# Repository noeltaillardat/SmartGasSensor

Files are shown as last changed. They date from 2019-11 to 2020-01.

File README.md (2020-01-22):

# SmartGasSensor
#### Arduino shield with gas sensing and LoRa connection.

On this github, you will find KiCad files to print your PCB and Arduino files to upload code to use the shield.

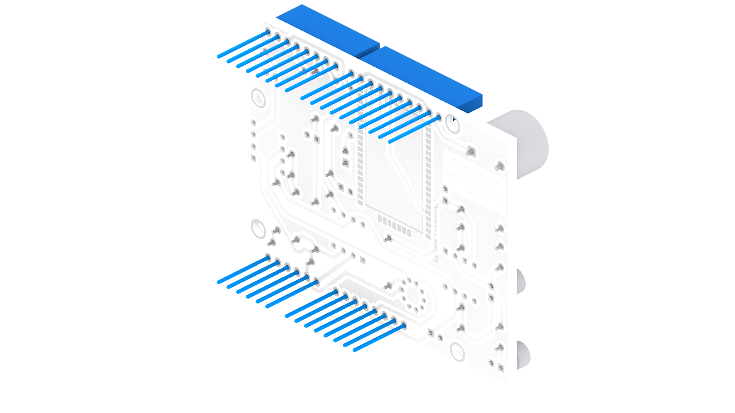
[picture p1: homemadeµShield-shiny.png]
Shield


## Functionalities
* Gas sensor + Electrical noise reduction + Temperature setting
* Warning trigger + visual warning 
* LoRa communication + TTN connection
* Buzzer can be activated

### Gas sensor + Electrical noise reduction
Gas sensor made at the AIME whiteroom of Toulouse.

On the shield, filters are made to reduce the electrical noise. There is a passive filter to cancel HF noise at the start of the circuit. An active filter with an Op-Amp is on to be more efficient. The gain can be modified with the potentiometer named *PT1*.
A passive filter at the end of the circuit is used to filter noise induced by the circuit.

The temperature can be set to improve gas recognition with *Gas_Temp_Target*.
The feedback loop gain can be modified with the *PT2* potentiometer.

### LoRa communication + TTN connection
You will find as well *ttn_script.js* to use on the TheThingsNetwork console to decrypt the data.

The Arduino code needs to be updated with your app and network session key foundable on the TTN console.
The activation method needs to be set to ABP. 

### Warning trigger + visual warning 
The warning can be set with *Gas_Trigger_Offset* to set the estimated thresold value.

An hysteresis has been made to be sure that the warning do not go on and on multiple times. 
This can be set with *Gas_Trigger_Diff*.
In case of limited amplitude of the hysteresis, the potentiometers *PT3* and *PT4* can be changed to adapt it to your use.

A LED on board have visual indication of the warning

### Buzzer can be activated
A buzzer can be activated with a *analogWrite* command.

A usage would be to set it to ring when the warning goes on, or when the warning is on.
Another can be to ring when the LoRa connection fails.

## Routing & schematics

Below is the schematic of our shield, including all the features explained above.

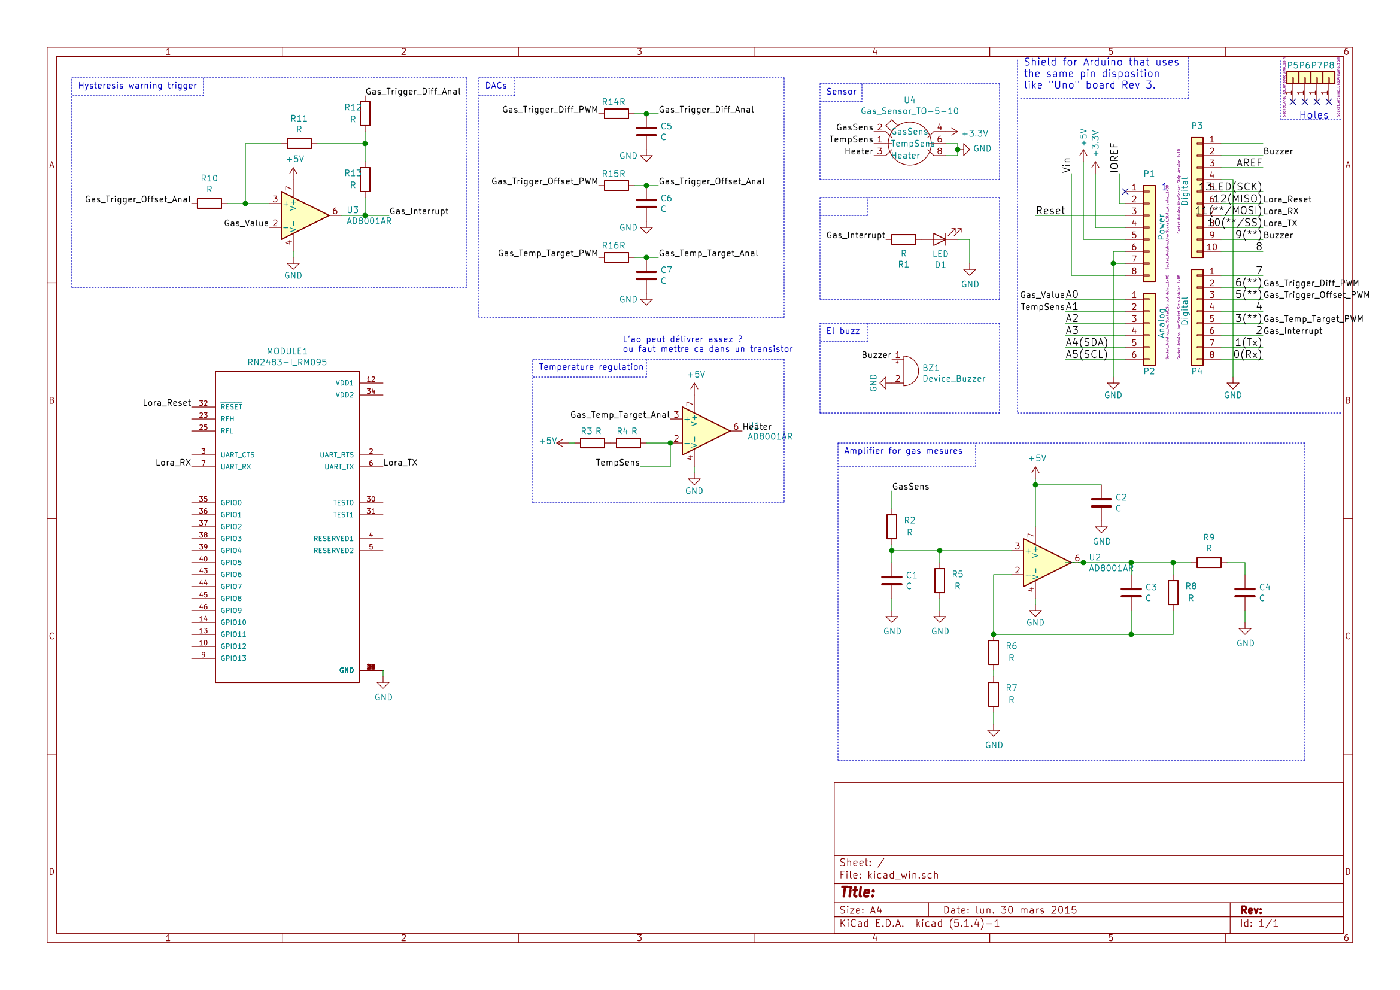
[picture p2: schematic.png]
Schematic


From there, the routing of our shield is achieved as shown below:

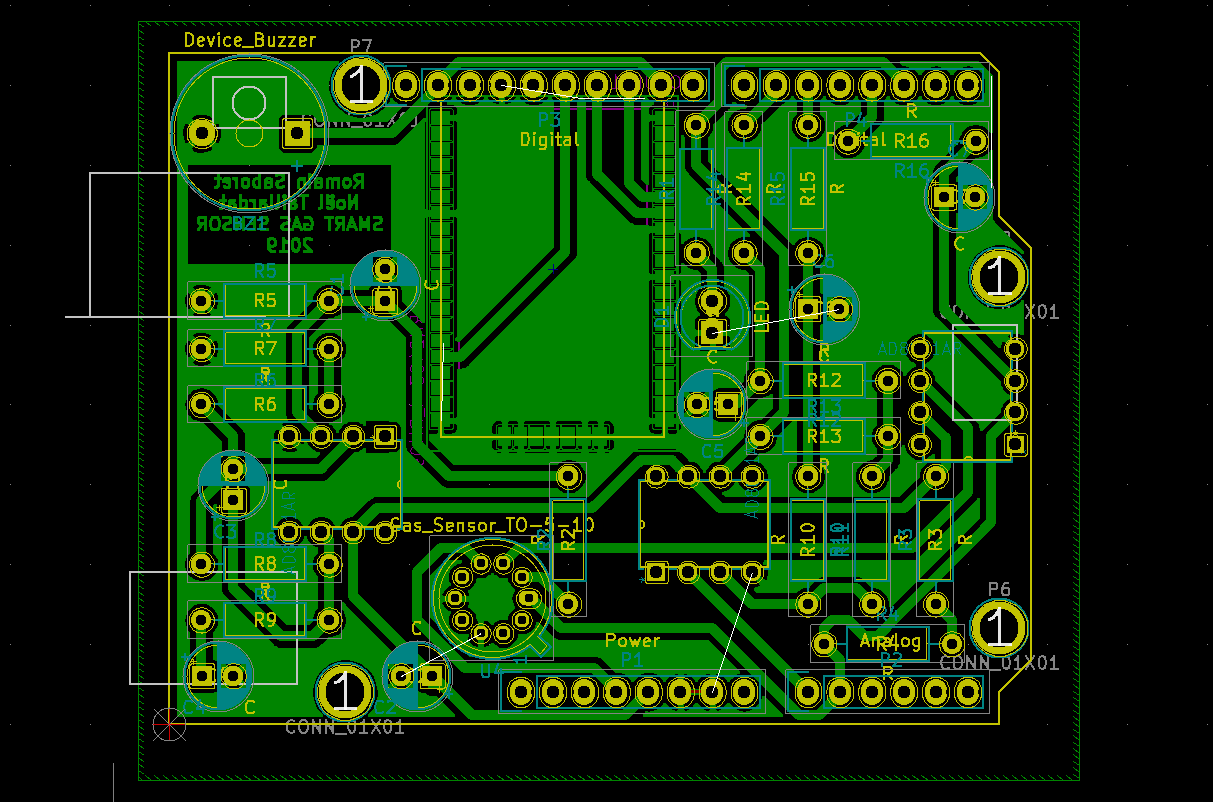
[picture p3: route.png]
Routes


Here, a 3D view (from Blender) of the shield: 

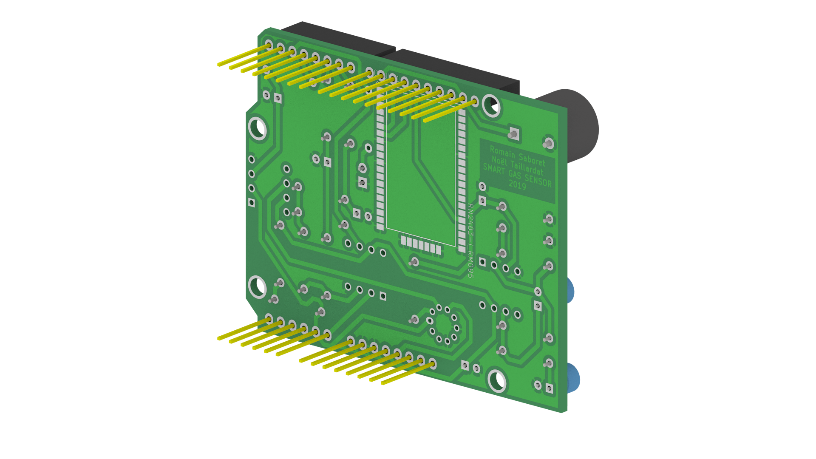
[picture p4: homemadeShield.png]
Final view


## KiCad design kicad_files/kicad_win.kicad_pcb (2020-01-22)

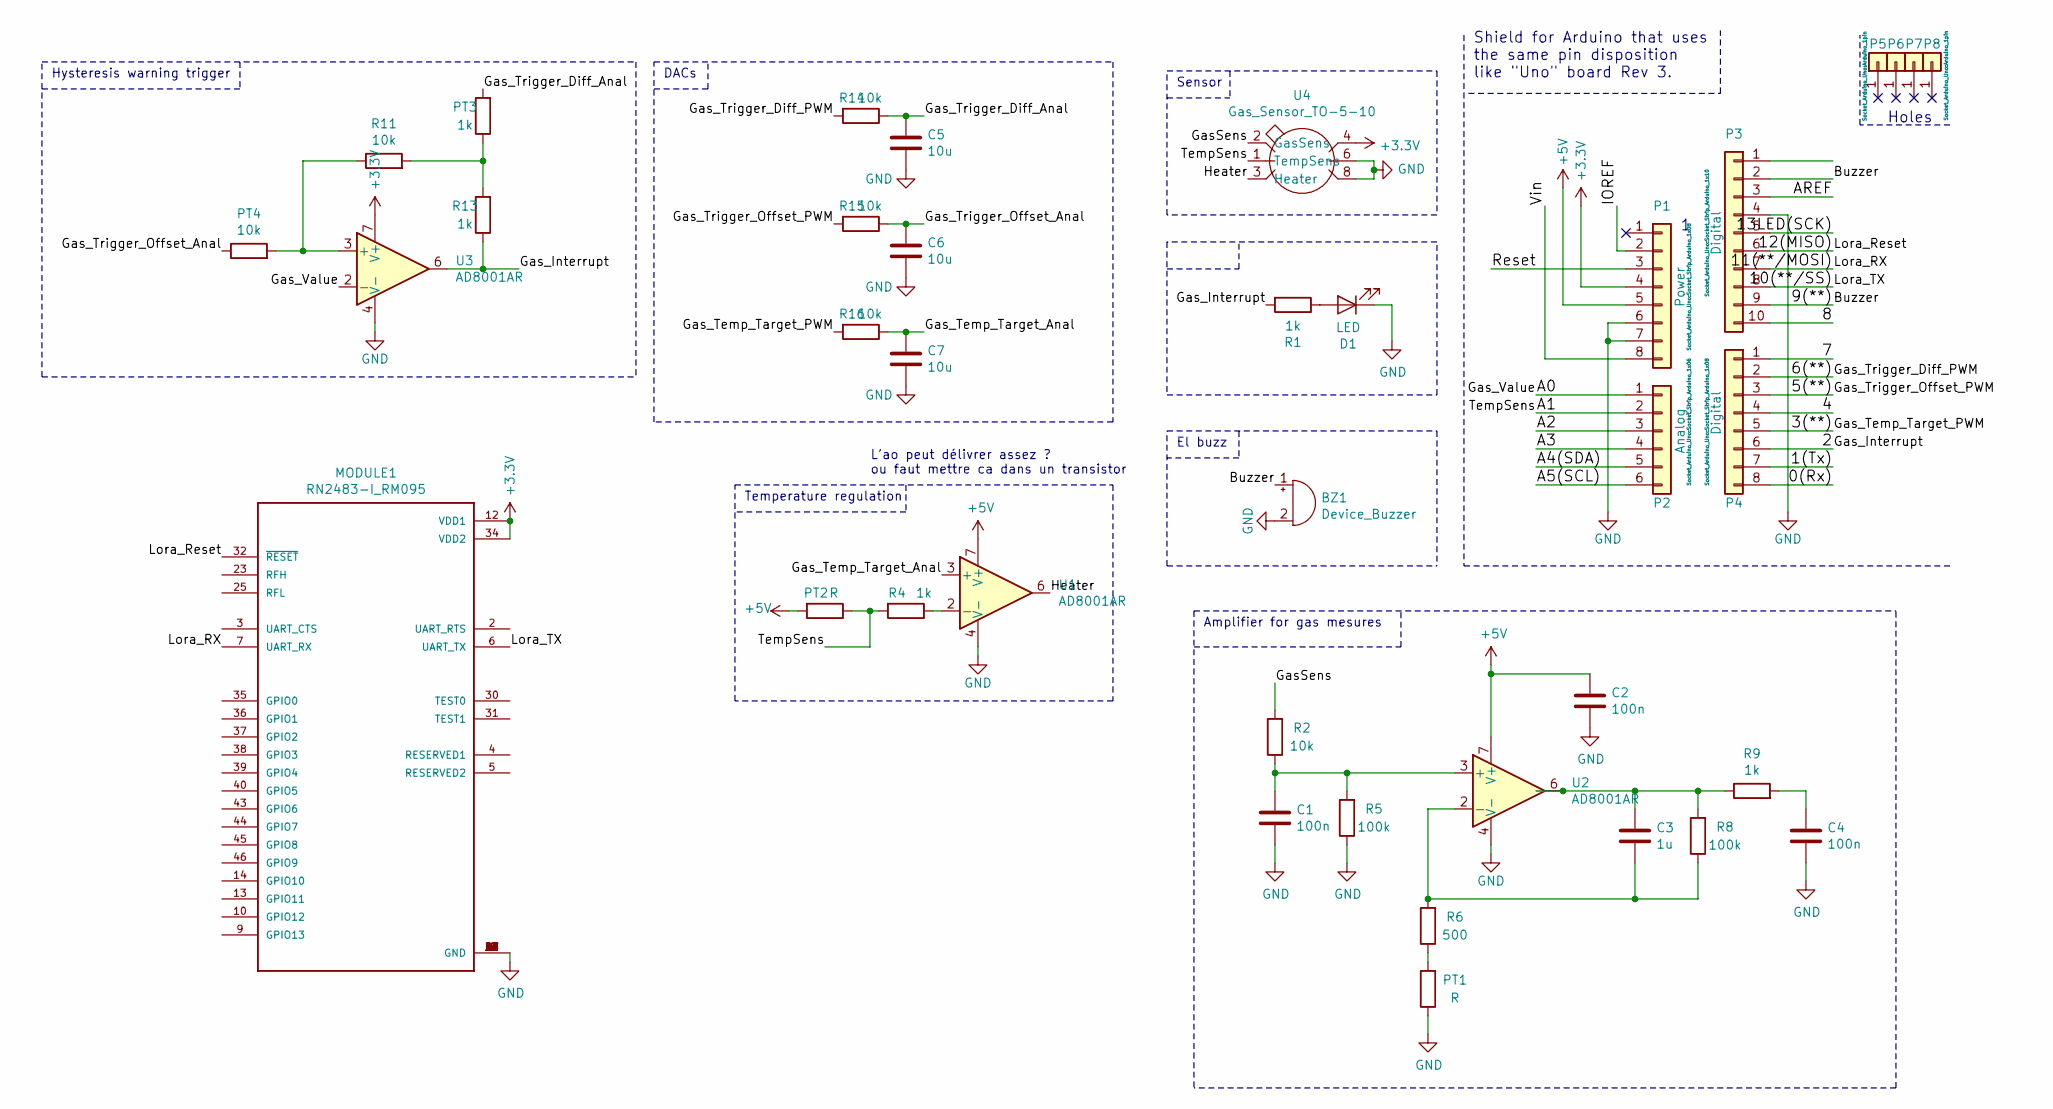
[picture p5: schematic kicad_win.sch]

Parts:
BZ1: Device_Buzzer; Buzzer_12x9.5RM7.6
C1, C2, C4: 100n; CP_Radial_D5.0mm_P2.50mm
C3: 1u; CP_Radial_D5.0mm_P2.50mm
C5, C6, C7: 10u; CP_Radial_D5.0mm_P2.50mm
D1: LED; LED_D5.0mm
MODULE1: RN2483-I_RM095; MICROCHIP_RN2483-I%2fRM095
P1: Power; Socket_Strip_Arduino_1x08
P2: Analog; Socket_Strip_Arduino_1x06
P3: Digital; Socket_Strip_Arduino_1x10
P4: Digital; Socket_Strip_Arduino_1x08
P5, P6, P7, P8: CONN_01X01; Arduino_1pin
PT1, PT2: R; R_Axial_DIN0207_L6.3mm_D2.5mm_P10.16mm_Horizontal
PT3: 1k; R_Axial_DIN0207_L6.3mm_D2.5mm_P10.16mm_Horizontal
PT4: 10k; R_Axial_DIN0207_L6.3mm_D2.5mm_P10.16mm_Horizontal
R1, R4, R9, R13: 1k; R_Axial_DIN0207_L6.3mm_D2.5mm_P10.16mm_Horizontal
R2, R11, R14, R15, R16: 10k; R_Axial_DIN0207_L6.3mm_D2.5mm_P10.16mm_Horizontal
R5, R8: 100k; R_Axial_DIN0207_L6.3mm_D2.5mm_P10.16mm_Horizontal
R6: 500; R_Axial_DIN0207_L6.3mm_D2.5mm_P10.16mm_Horizontal
U1, U2, U3: AD8001AR; PDIP-8_N
U4: Gas_Sensor_TO-5-10; TO-5-10

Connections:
+3V3: MODULE1.12 (VDD1), MODULE1.34 (VDD2), P1.4, U3.7 (V+), U4.4
+5V: C2.1, P1.5, PT2.2, U1.7 (V+), U2.7 (V+)
/0(Rx): P4.8
/1(Tx): P4.7
/2: P4.6, R1.2, R13.1, U3.6
/3(**): P4.5, R16.2
/4: P4.4
/5(**): P4.3, R15.2
/6(**): P4.2, R14.2
/7: P4.1
/8: P3.10
/9(**): BZ1.1 (-), P3.2, P3.9
/10(**/SS): MODULE1.6 (UART_TX), P3.8
/11(**/MOSI): MODULE1.7 (UART_RX), P3.7
/12(MISO): MODULE1.32 (~RESET~), P3.6
/13LED(SCK): P3.5
/A0: P2.1, U3.2 (-)
/A1: P2.2, PT2.1, R4.2, U4.1 (TempSens)
/A2: P2.3
/A3: P2.4
/A4(SDA): P2.5
/A5(SCL): P2.6
/AREF: P3.3
/GasSens: R2.2, U4.2 (GasSens)
/Gas_Temp_Target_Anal: C7.1, R16.1, U1.3 (+)
/Gas_Trigger_Diff_Anal: C5.1, PT3.2, R14.1
/Gas_Trigger_Offset_Anal: C6.1, PT4.1, R15.1
/Heater: U1.6, U4.3 (Heater)
/IOREF: P1.2
/Reset: P1.3
/Vin: P1.8
GND: BZ1.2 (+), C1.2, C2.2, C4.2, C5.2, C6.2, C7.2, D1.1 (K), MODULE1.1 (GND), MODULE1.8 (GND), MODULE1.11 (GND), MODULE1.20 (GND), MODULE1.21 (GND), MODULE1.22 (GND), MODULE1.24 (GND), MODULE1.26 (GND), MODULE1.27 (GND), MODULE1.28 (GND), MODULE1.33 (GND), MODULE1.41 (GND), MODULE1.47 (GND), P1.6, P1.7, P3.4, PT1.1, R5.1, U1.4 (V-), U2.4 (V-), U3.4 (V-), U4.6, U4.8
unnamed: C1.1, R2.1, R5.2, U2.3 (+)
unnamed: C3.1, R8.2, R9.1, U2.6
unnamed: C3.2, R6.2, R8.1, U2.2 (-)
unnamed: C4.1, R9.2
unnamed: D1.2 (A), R1.1
unnamed: PT1.2, R6.1
unnamed: PT3.1, R11.2, R13.2
unnamed: PT4.2, R11.1, U3.3 (+)
unnamed: R4.1, U1.2 (-)

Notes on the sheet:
Holes
Shield for Arduino that uses the same pin disposition like "Uno" board Rev 3.
Temperature regulation
Hysteresis warning trigger
El buzz
L'ao peut délivrer assez ? ou faut mettre ca dans un transistor
DACs
Sensor
Amplifier for gas mesures

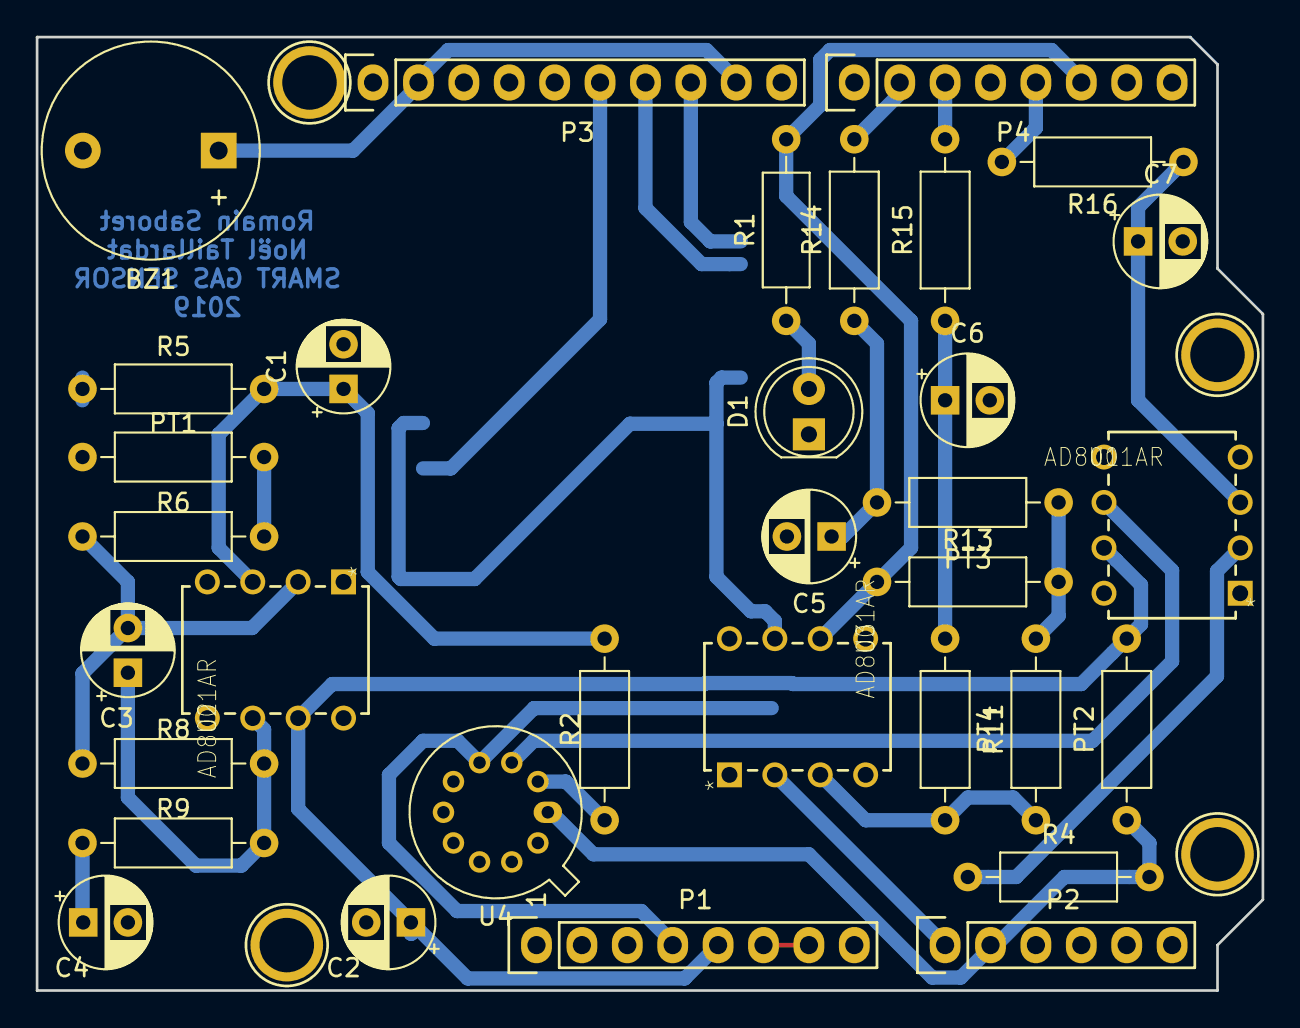
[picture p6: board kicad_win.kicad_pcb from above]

Board: 2 copper layers, 68.6 x 53.3 mm, 38 parts (1 on the bottom side), 27 nets.

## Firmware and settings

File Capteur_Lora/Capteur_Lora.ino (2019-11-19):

#include <TheThingsNetwork.h>
#include <SoftwareSerial.h>

// Pins
#define RX            10
#define TX            11
#define CAPTEUR       2
#define CAPTEUR_VALUE A0

// Interruption mode. Choose in LOW CHANGE RISING FALLING
#define MODE RISING

// Set your DevAddr, NwkSKey, AppSKey and the frequency plan
const char *devAddr = "26011ED8";
const char *nwkSKey = "B4A356C5FBC0A4B24B4EF83D59A0CA06";
const char *appSKey = "BEB8D4D7C052339D4510FD0FCD4D6E10";

SoftwareSerial loraSerial(RX, TX);
#define debugSerial Serial

#define freqPlan TTN_FP_EU868

TheThingsNetwork ttn(loraSerial, debugSerial, freqPlan);

/*  LoRa frame: 
 *  
 *  Payload[0]
 *  W3 W2 W1 W0 0  0  P9 P8
 *  Payload[1]
 *  P7 P6 P5 P4 P3 P2 P1 P0
 *  
 *  (W: Warning flag)
 */
 
byte payload[2] = { 0, 0 };

void readSensor() {
  int capteur = analogRead(CAPTEUR_VALUE);
  debugSerial.println("Capteur: " + (String)(capteur));

  payload[0] &= ~(0x3);
  payload[0] |= capteur >> 8; 
  
  payload[1] = capteur;
  debugSerial.println(
    "Payload_0: " + (String)(payload[0]) 
   +" Payload_1: " + (String)(payload[1]));

}

void gasInterrupt() 
{
  // Rise warning flag on last bit
  payload[0] |= 0xF0;
}

void setup()
{
  loraSerial.begin(57600);
  debugSerial.begin(9600);

  // Wait a maximum of 10s for Serial Monitor
  while (!debugSerial && millis() < 10000) {}

  debugSerial.println("-- PERSONALIZE");
  ttn.personalize(devAddr, nwkSKey, appSKey);

  debugSerial.println("-- STATUS");
  ttn.showStatus();

  // Interrupt when gas is detected
  attachInterrupt(digitalPinToInterrupt(CAPTEUR), gasInterrupt, MODE);
}

void loop()
{
  debugSerial.println("-- LOOP");
  
  // Update payload global value
  readSensor();  
  // Send payload over TTN
  ttn.sendBytes(payload, sizeof(payload));
  // Reset warning flag
  payload[0] &= ~(0xF0);
   
  delay(5000);
}

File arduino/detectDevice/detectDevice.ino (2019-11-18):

#include <TheThingsNetwork.h>
#include <SoftwareSerial.h>

#define TX_PIN           11   //RN2483A TX pin
#define RX_PIN           10   //RN2483A RX pin
SoftwareSerial loraSerial(RX_PIN, TX_PIN); //Serial link with the LoRa module

//#define loraSerial Serial
#define debugSerial Serial

// Replace REPLACE_ME with TTN_FP_EU868 or TTN_FP_US915
#define freqPlan TTN_FP_EU868

TheThingsNetwork ttn(loraSerial, debugSerial, freqPlan);

void setup()
{
  loraSerial.begin(57600);
  debugSerial.begin(9600);
}

void loop()
{
  debugSerial.println("Device Information");
  debugSerial.println();
  ttn.showStatus();
  debugSerial.println();
  debugSerial.println("Use the EUI to register the device for OTAA");
  debugSerial.println("-------------------------------------------");
  debugSerial.println();

  delay(10000);
}

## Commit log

2019-11-18 Small arduino program detecting our device
2019-11-19 Arduino file for transmitting gas value and warning
2019-11-19 Kicad de romain de base
    [lora.kicad_pcb, lora.sch]
2019-11-29 last actif kicad
    [kicad_win.kicad_pcb, kicad_win.sch]
2019-12-01 new version of the schematic
    [kicad_win.kicad_pcb, kicad_win.sch]
2020-01-21 Complete electronic circuits
    [kicad_win.kicad_pcb, kicad_win.sch]
2020-01-22 probably final
    [kicad_win.kicad_pcb, kicad_win.sch]
